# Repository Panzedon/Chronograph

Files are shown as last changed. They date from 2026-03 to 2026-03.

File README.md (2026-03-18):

# ⚡ Хронограф для страйкбола / Airsoft Chronograph

[🇺🇦 Українська](#-українська) | [🇬🇧 English](#-english)

---

## 🇺🇦 Українська

### 📌 Опис проєкту
Хронограф для страйкбольних куль 6 мм на базі мікроконтролера **STM8S103F3P6**.  
Живлення від **USB Type-C**, використання **двох ІЧ-променів (інфрачервоних)** для фіксації польоту кульки.

🎯 **Можливості:**
- 📏 Вимірювання **швидкості кулі** (м/с)
- 💥 Розрахунок **енергії пострілу** (Дж)
- 🔫 Визначення **скорострільності** (пострілів за хвилину / RPM)
- 🧠 **Енергонезалежна пам'ять:** пристрій запам'ятовує останній обраний режим та вагу кульки після вимкнення живлення.
- ⚡ **Миттєвий розрахунок:** при пострілі система одночасно обчислює швидкість, енергію та скорострільність.

### 🔧 Керування
- 🔴 **Ліва кнопка (Кнопка 1)** — вмикає/вимикає семисегментний індикатор.
- 🔵 **Права кнопка (Кнопка 2):**
    - **Коротке натискання** — перемикання між режимами відображення (Швидкість / Енергія / Скорострільність).
    - **Довге утримання** — перехід у режим **задання ваги кульки** (у грамах). 
    - **Вибір ваги:** доступні значення — **0.2г, 0.23г, 0.25г, 0.28г, 0.3г**.
    - **Збереження:** повторне довге утримання зберігає обрану вагу та повертає до основного режиму.

### ⚙️ Технічні характеристики

| Параметр | Значення |
|---|---|
| Мікроконтролер | STM8S103F3P6 |
| Живлення | USB Type-C |
| Датчики | 2 ІЧ-промені |
| Калібр | 6 мм BB (страйкбол) |

### 📂 Структура проєкту
- **Altium** — принципова схема та плата (Altium Designer) і системні файли.
- **Docs** - архів сверління для заводу, BOM і документація
- **VsCode** — середовище розробки (C, COSMIC, stm8flash, ST-LINK) і код програми.

## 📽️ Відео демонстрація роботи

У цьому відео продемонстровано процес вимірювання швидкості та скорострільності страйкбольного приводу (AEG) за допомогою розробленого хронографа. 

Дивитися відео (https://youtube.com/shorts/bznoCWF54Is)

✍️ **Автор:** Матвій Шульга

---

## 🇬🇧 English

### 📌 Project description
Chronograph for 6 mm airsoft BBs based on **STM8S103F3P6** microcontroller.  
Powered via **USB Type-C**, uses **two IR (Infrared) beams** to detect BB flight.

🎯 **Features:**
- 📏 Measure **BB velocity** (m/s)
- 💥 Calculate **shot energy** (Joules)
- 🔫 Measure **rate of fire** (rounds per minute / RPM)
- 🧠 **Non-volatile memory:** the device remembers the last measurement mode and BB weight setting after power off.
- ⚡ **Instant calculation:** a single shot triggers simultaneous calculation of velocity, energy, and rate of fire.

### 🔧 Controls
- 🔴 **Left Button (Button 1)** — LED indicator power on/off.
- 🔵 **Right Button (Button 2):**
    - **Short press** — toggles between display modes (Velocity / Energy / Rate of Fire).
    - **Long hold** — enters **BB weight setting mode** (in grams).
    - **Weight presets:** **0.2g, 0.23g, 0.25g, 0.28g, 0.3g**.
    - **Saving:** long hold again to save the selected weight and return to the measurement mode.

### ⚙️ Technical specifications

| Parameter | Value |
|---|---|
| Microcontroller | STM8S103F3P6 |
| Power supply | USB Type-C |
| Sensors | 2 IR beams |
| Caliber | 6 mm BBs |

### 📂 Project Structure
- **Altium** — Schematic design, PCB layout (Altium Designer), and project system files.
- **Docs** — Manufacturing files (Drill/Gerber), Bill of Materials (BOM), and technical documentation.
- **VsCode** — Development environment (C, COSMIC, stm8flash, ST-LINK) and source code.

## 📽️ Video Demonstration

This video demonstrates the measurement of muzzle velocity and rate of fire (ROF) for an airsoft replica (AEG) using the developed chronograph.

Watch Video (https://youtube.com/shorts/bznoCWF54Is)

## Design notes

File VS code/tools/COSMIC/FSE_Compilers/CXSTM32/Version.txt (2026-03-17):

---------------------------------
STM32 COSMIC C 32K Compiler
Version: 4.3.12 Date: 14 Dec 2023
---------------------------------
COSMIC Software CORTEX-M C Cross Compiler (LIMITED) V4.3.12 - 14 Dec 2023 - Win32-F
COSMIC Software CORTEX-M C Parser (LIMITED) V4.13.7 - 08 Nov 2023 - Win32-F
COSMIC Software CORTEX-M Code Generator (LIMITED) V4.3.12 - 14 Dec 2023 - Win32-F
COSMIC Software CORTEX-M Optimizer V4.2.12 - 14 Dec 2023 - Win32
COSMIC Software CORTEX-M Macro-Assembler (LIMITED) V4.8.1 - 14 Dec 2023 - Win32-F
COSMIC Software Linker (LIMITED) V4.12.1 - 02 Feb 2023 - Win32-F
COSMIC Software Hexa Translator V4.5.7 - 06 Sep 2023 - Win32
COSMIC Software Absolute Listing V4.5.7 - 06 Sep 2023 - Win32
COSMIC Software Librarian V4.5.7 - 06 Sep 2023 - Win32
COSMIC Software Absolute C Listing V4.5.7 - 06 Sep 2023 - Win32
COSMIC Software Object Inspector V4.5.7 - 06 Sep 2023 - Win32
COSMIC Software Print Debug Info V4.5.7 - 06 Sep 2023 - Win32
COSMIC Software ELF/DWARF Converter V4.7.6 - 11 Jan 2022 - Win32

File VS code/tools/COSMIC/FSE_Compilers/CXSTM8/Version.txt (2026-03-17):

--------------------------------------
COSMIC STM8 C Compiler Special Edition
Version: 4.6.5 Date: 22 May 2025
--------------------------------------
COSMIC Software STM8 C Cross Compiler (Special Edition) V4.6.5 - 22 May 2025 - Win32-F
COSMIC Software STM8 C Parser (Special Edition) V4.13.3 - 22 May 2025 - Win32-F
COSMIC Software STM8 Code Generator (Special Edition) V4.6.5 - 22 May 2025 - Win32-F
COSMIC Software STM8 Optimizer V4.6.5 - 22 May 2025 - Win32
COSMIC Software STM8 Macro-Assembler (Special Edition) V4.8.1 - 14 Dec 2023 - Win32-F
COSMIC Software Linker (Special Edition) V4.12.2 - 05 May 2025 - Win32-F
COSMIC Software Hexa Translator V4.5.8 - 27 Jun 2024 - Win32
COSMIC Software Absolute Listing V4.5.8 - 27 Jun 2024 - Win32
COSMIC Software Librarian V4.5.8 - 27 Jun 2024 - Win32
COSMIC Software Absolute C Listing V4.5.8 - 27 Jun 2024 - Win32
COSMIC Software Object Inspector V4.5.8 - 27 Jun 2024 - Win32
COSMIC Software Print Debug Info V4.5.8 - 27 Jun 2024 - Win32
COSMIC Software ELF/DWARF Converter V4.7.6 - 11 Jan 2022 - Win32

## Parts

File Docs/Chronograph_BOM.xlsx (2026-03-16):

Internal reference |  |  |  |  |  |  |  |  |  |  |  |  | BPC.001.BAT.001
Assembly variant |  |  |  |  |  |  |  |  |  |  |  |  | 3
Engineer(s) | Matvei Shulga
Document timestamp
Technical information |  |  |  |  |  |  |  | Additional information |  |  | Logistics information
 |  |  |  |  |  |  |  |  |  |  | Ajax warehouse |  | Replacement options
Designator | Manufacturer | Part Number | Value | Tolerance | Voltage | Component Type | Package | Quantity | Comment | Description | Ajax_1C_ID | Ajax_1C_PN | Replacement
C1 |  |  | 22µF | 20% | 10V |  | 1206 | 1 | TAJA226M010RNJ | Cap Tant Solid 22uF 10V A CASE 20%( 3.2 X 1.6 X 1.6mm) Inward L SMD 3216-18 3 Ohm 125C T/R |  |  | NONE
C2 |  |  | 10µF | 10% | 35V |  | 1206 | 1 | GCJ31CD7YA106KE02L | Ceramic Capacitor, Ceramic, 35V, 10% +Tol, 10% -Tol, X7T, 22/-33% TC, 10uF, Surface Mount, 1206 |  |  | NONE
C3, C6, C8, C10, C11 |  |  | 100nF |  |  |  | 1206 | 5 | UMK316B7104KLHT | Ceramic Capacitor, Multilayer, Ceramic, 50V, 10% +Tol, 10% -Tol, X7R, 15% TC, 0.1uF, Surface Mount, 1206 |  |  | NONE
C4, C7 |  |  | 1µF | 5% | 10V |  | 1206 | 2 | 1206ZC105JAT2A | Ceramic Capacitor, Multilayer, Ceramic, 10V, 5% +Tol, 5% -Tol, X7R, 15% TC, 1uF, Surface Mount, 1206 |  |  | NONE
C5 |  |  | 680nF |  |  |  | 0805 | 1 | CC0805KKX7R6BB684 | Ceramic Capacitor, Multilayer, Ceramic, 10V, 10% +Tol, 10% -Tol, X7R, 15% TC, 0.68uF, Surface Mount, 0805 |  |  | NONE
C9 |  |  | 100µF | 20% | 6.3V |  | 1206 | 1 | TLJA107M006R0500 | Cap Tant Solid 100uF 6.3V A CASE 20% (3.2 X 1.6 X 1.6mm) Inward L SMD 3216-18 0.5 Ohm 125C T/R |  |  | NONE
C12, C13 |  |  | 100pF |  |  |  | 1206 | 2 | 12063A101KAT2A | Ceramic Capacitor, Multilayer, Ceramic, 25V, 10% +Tol, 10% -Tol, C0G, 30ppm/Cel TC, 0.0001uF, Surface Mount, 1206 |  |  | NONE
D1 |  |  |  |  |  |  | SOT-143 | 1 | SP0503BAHTG | SP050xBA Series 8.5 V 30 pF Triple Uni-Directional TVS Avalanche Diode-SOT143-4 |  |  | NONE
DS1 | Everlight | ELT-315USOWA/S530-A3 |  |  |  |  |  | 1 | 7 Segment Indicator | Display |  |  | NONE
IC1 | TITAN MICRO ELECTRONICS | TM1637 (SOP) |  |  |  |  |  | 1 | TM1637 | Integrated Circuit |  |  | NONE
J1 |  |  |  |  | 20V |  |  | 1 | USB4110-GF-A | USB Connector, 16 Contact(s), Male, Right Angle, Surface Mount Terminal, Locking, Receptacle |  |  | NONE
LED1, LED2 | Everlight | IR333/H0-A |  |  |  |  |  | 2 | IR333 | LED |  |  | NONE
P1 |  |  |  |  |  | Standard |  | 1 | ST-Link V2 |  |  |  | NONE
Q1, Q2 | Everlight | PT333-3C |  |  |  |  |  | 2 | PT333-3C | Phototransistor |  |  | NONE
R1, R5, R7, R8, R10, R12, R13 |  |  | 10k | 1% | 200V |  | 1206 | 7 | AC1206FR-1310KL | Res Thick Film 1206 10K Ohm 1% 0.25W(1/4W) ±100ppm/°C Pad SMD T/R Automotive AEC-Q200 |  |  | NONE
R2, R3 |  |  | 5.1k | 1% | 200V |  | 1206 | 2 | ESR18EZPF5101 | Res Thick Film 1206 5.1K Ohm 1% 0.5W(1/2W) ±100ppm/C Pad SMD T/R Automotive AEC-Q200 |  |  | NONE
R4, R9 |  |  | 100 | 5% | 200V |  | 1206 | 2 | RC3216J101CS | Res Thick Film 1206 100 Ohm 5% 1/4W ±100ppm/°C Molded SMD T/R |  |  | NONE
R6, R11 |  |  | 1k | 0.1% | 25V |  | 1206 | 2 | RP73D2B1K0BTG | Res Thin Film 1206 1K Ohm 0.1% 0.25W(1/4W) ±15ppm/C Pad SMD Cut Tape Medical |  |  | NONE
SW1, SW2 |  |  |  |  |  |  |  | 2 | FSM4JSMATR | Keypad Switch, 1 Switches, SPST, Momentary-tactile, 0.05A, 24VDC, 2.06N, Solder Terminal, Surface Mount-straight |  |  | NONE
U1 |  |  |  |  |  |  | SOP | 1 | AMS1117-3.3 | Fixed Positive LDO Regulator, 3.3V, 1.3V Dropout, PDSO3 |  |  | NONE
U2 |  |  |  |  |  | Standard | TSSOP-20 STMicroelectronics | 1 | STM8S103F3P6 | STM8 series Microcontroller IC 8-Bit 16MHz 8KB (8K x 8) FLASH 20-TSSOP |  |  | NONE
U3 |  |  |  |  |  |  | QFN | 1 | CP2104-F03-GM | USB-to-UART 1-CH 576byte FIFO 3.3V Automotive 24-Pin QFN EP Tube |  |  | NONE
U4 |  |  |  |  |  |  | SOP | 1 | LM393DT | Comparator, 2 Func, 9000uV Offset-Max, 1300ns Response Time, BIPolar, PDSO8 |  |  | NONE
VR1 | Bourns | 3362P-1-205LF |  |  |  |  |  | 1 | 3362P-1-205LF | Variable Resistor |  |  | NONE
 |  |  |  |  |  |  |  |  |  |  |  |  | NONE
 |  |  |  |  |  |  |  |  |  |  |  |  | NONE
 |  |  |  |  |  |  |  |  |  |  |  |  | NONE
 |  |  |  |  |  |  |  |  |  |  |  |  | NONE
 |  |  |  |  |  |  |  |  |  |  |  |  | NONE
 |  |  |  |  |  |  |  |  |  |  |  |  | NONE
 |  |  |  |  |  |  |  |  |  |  |  |  | NONE
 |  |  |  |  |  |  |  |  |  |  |  |  | NONE
 |  |  |  |  |  |  |  |  |  |  |  |  | NONE
 |  |  |  |  |  |  |  |  |  |  |  |  | NONE
 |  |  |  |  |  |  |  |  |  |  |  |  | NONE
 |  |  |  |  |  |  |  |  |  |  |  |  | NONE
 |  |  |  |  |  |  |  |  |  |  |  |  | NONE
 |  |  |  |  |  |  |  |  |  |  |  |  | NONE
 |  |  |  |  |  |  |  |  |  |  |  |  | NONE
 |  |  |  |  |  |  |  |  |  |  |  |  | NONE
 |  |  |  |  |  |  |  |  |  |  |  |  | NONE
 |  |  |  |  |  |  |  |  |  |  |  |  | NONE
 |  |  |  |  |  |  |  |  |  |  |  |  | NONE
 |  |  |  |  |  |  |  |  |  |  |  |  | NONE
 |  |  |  |  |  |  |  |  |  |  |  |  | NONE
 |  |  |  |  |  |  |  |  |  |  |  |  | NONE
 |  |  |  |  |  |  |  |  |  |  |  |  | NONE
 |  |  |  |  |  |  |  |  |  |  |  |  | NONE
 |  |  |  |  |  |  |  |  |  |  |  |  | NONE
 |  |  |  |  |  |  |  |  |  |  |  |  | NONE

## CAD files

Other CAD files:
VS code/tools/COSMIC/stsw-stm8069/STM8S_StdPeriph_Lib/Project/STM8S_StdPeriph_Template/STVD/Cosmic/stm8s103.stp
VS code/tools/COSMIC/stsw-stm8069/STM8S_StdPeriph_Lib/Project/STM8S_StdPeriph_Template/STVD/Raisonance/stm8s003.stp
VS code/tools/COSMIC/stsw-stm8069/STM8S_StdPeriph_Lib/Project/STM8S_StdPeriph_Template/STVD/Cosmic/stm8af52ax.stp
VS code/tools/COSMIC/stsw-stm8069/STM8S_StdPeriph_Lib/Project/STM8S_StdPeriph_Template/STVD/Raisonance/stm8af62ax.stp
VS code/tools/COSMIC/stsw-stm8069/STM8S_StdPeriph_Lib/Project/STM8S_StdPeriph_Template/STVD/Cosmic/stm8af626x.stp
VS code/tools/COSMIC/stsw-stm8069/STM8S_StdPeriph_Lib/Project/STM8S_StdPeriph_Template/STVD/Raisonance/stm8s207.stp
VS code/tools/COSMIC/stsw-stm8069/STM8S_StdPeriph_Lib/Project/STM8S_StdPeriph_Template/STVD/Cosmic/stm8s208.stp
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

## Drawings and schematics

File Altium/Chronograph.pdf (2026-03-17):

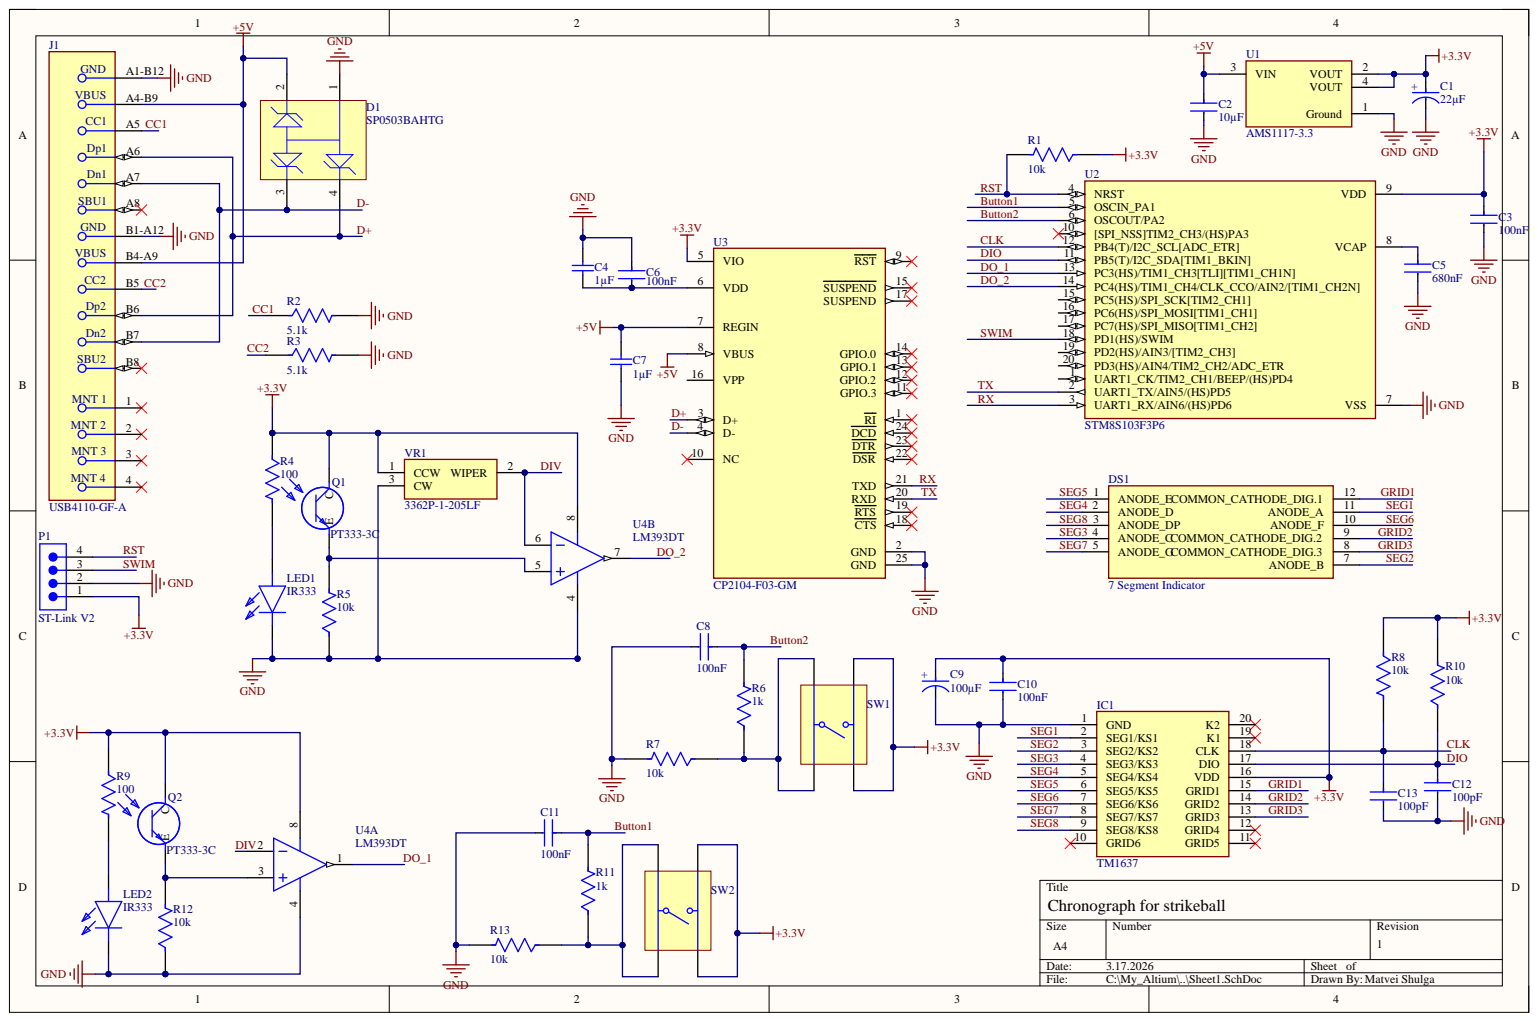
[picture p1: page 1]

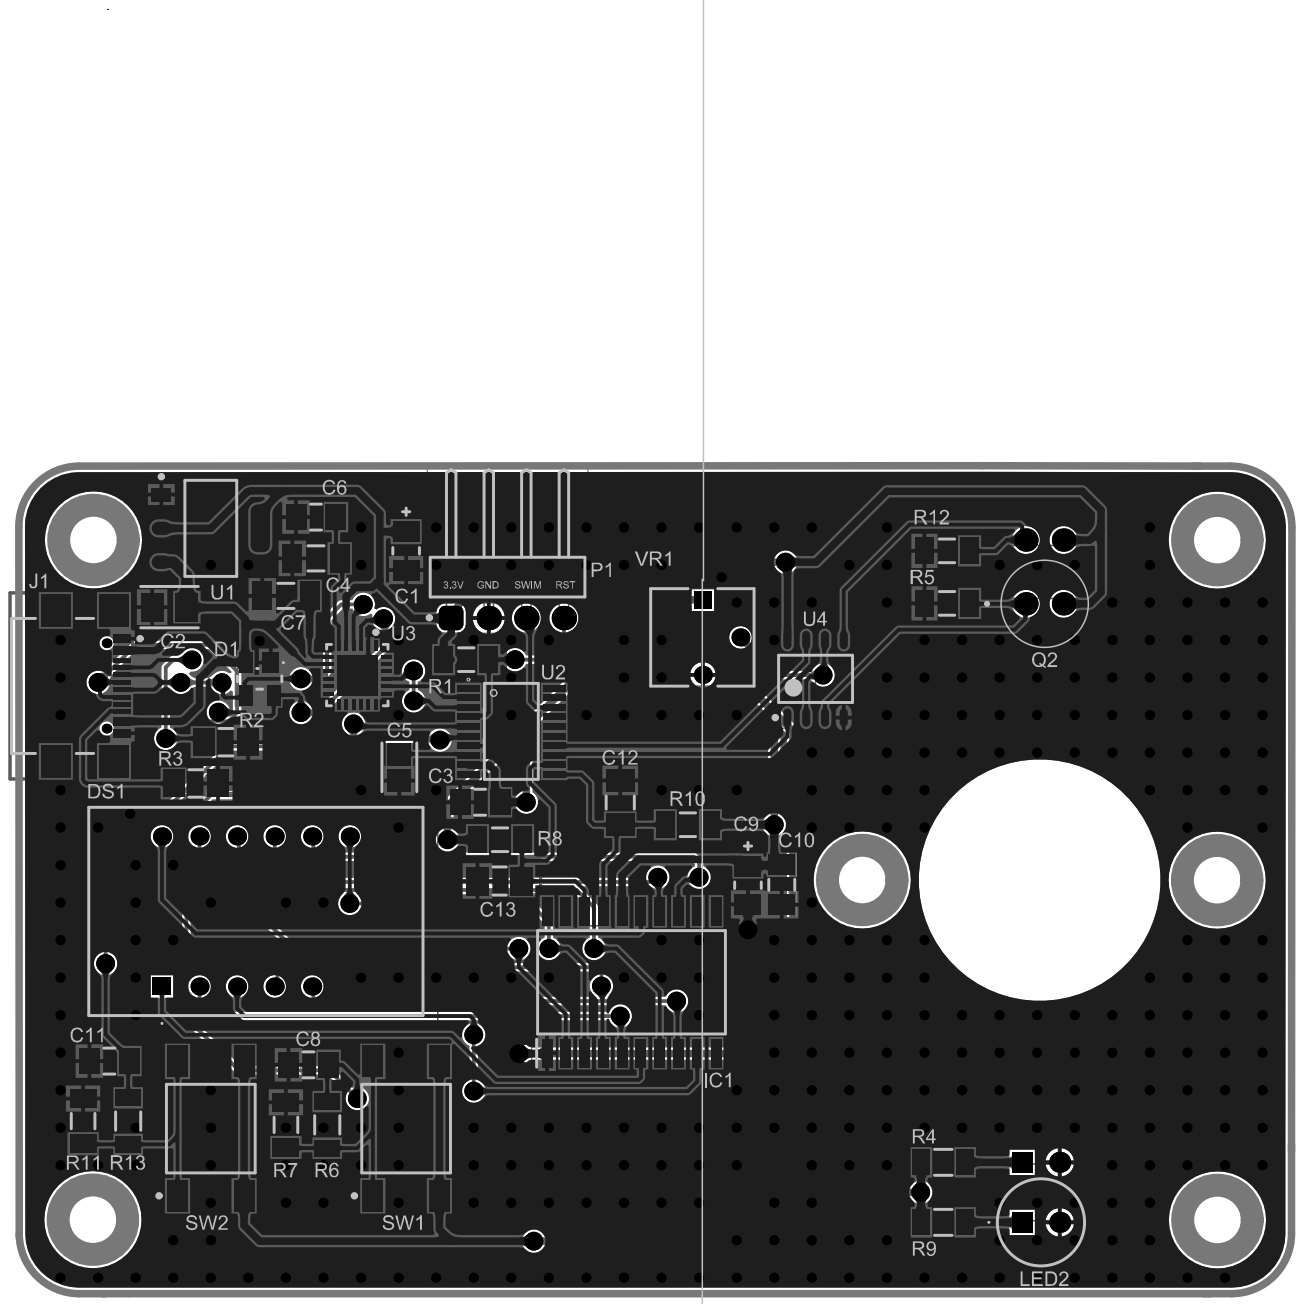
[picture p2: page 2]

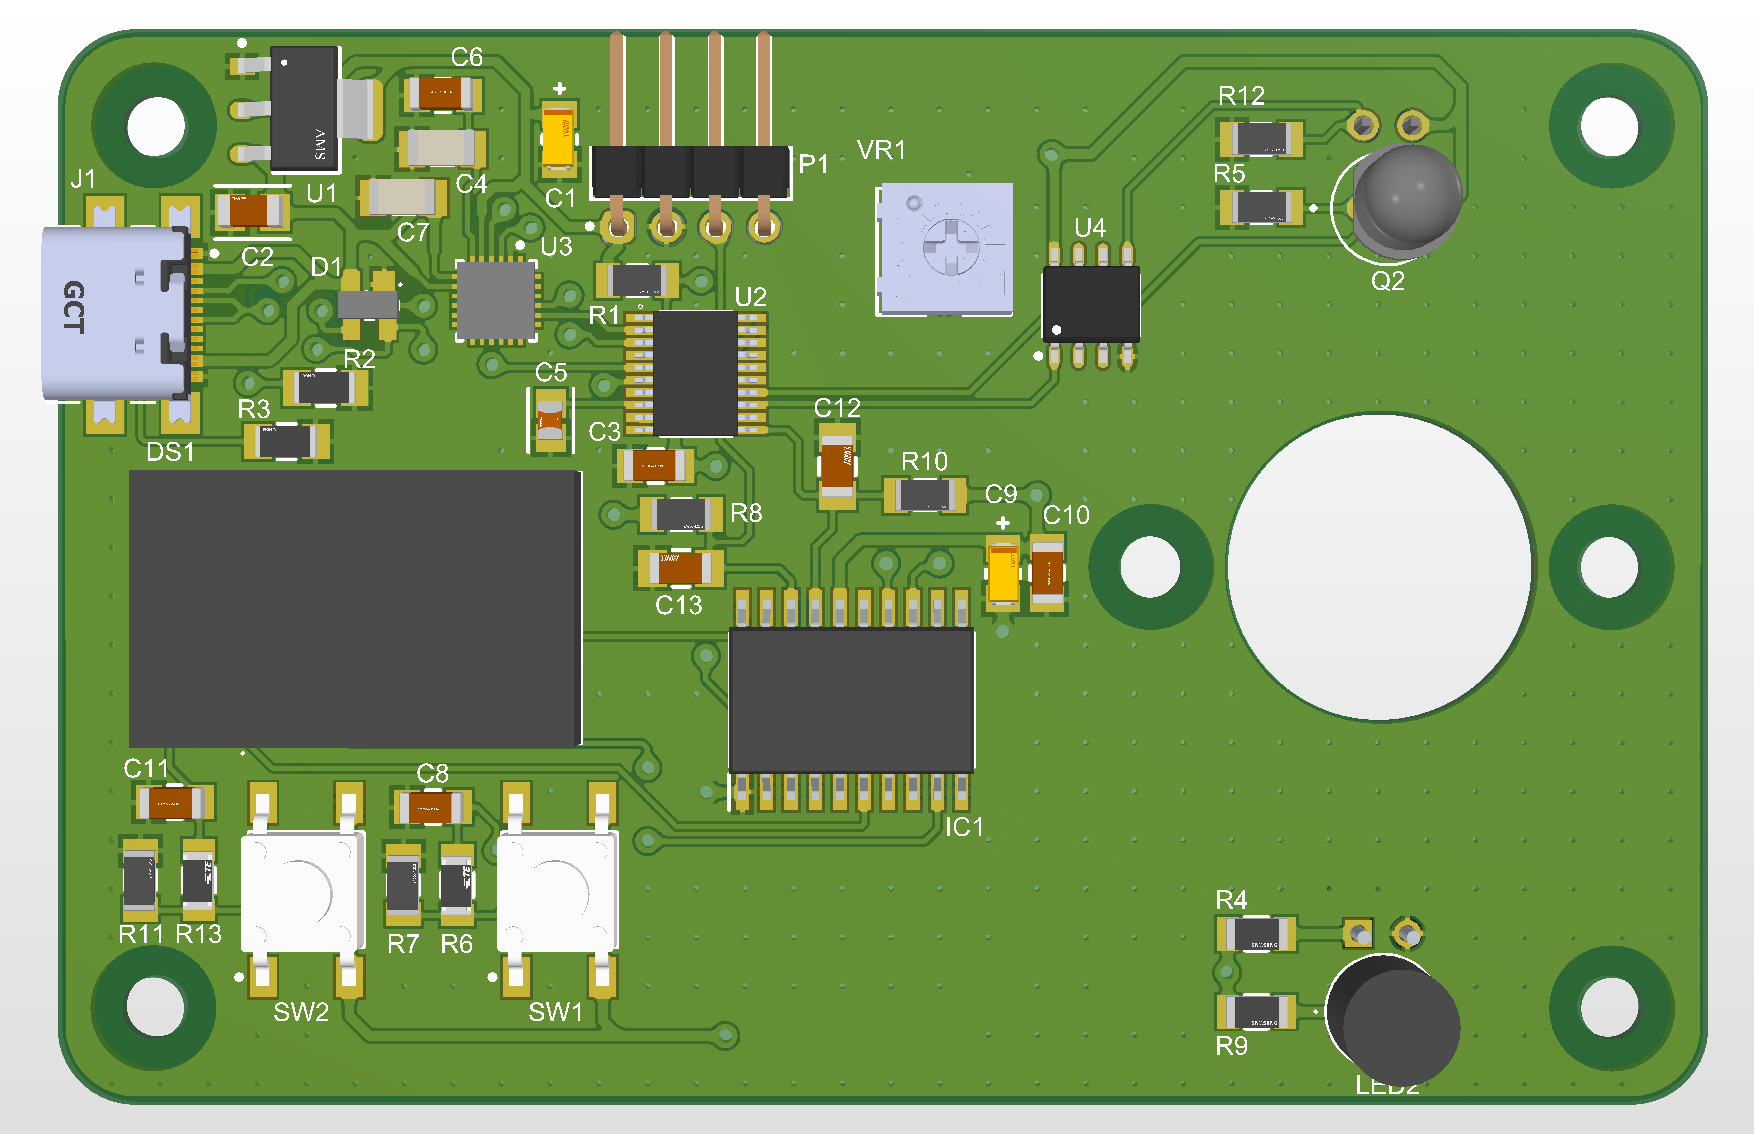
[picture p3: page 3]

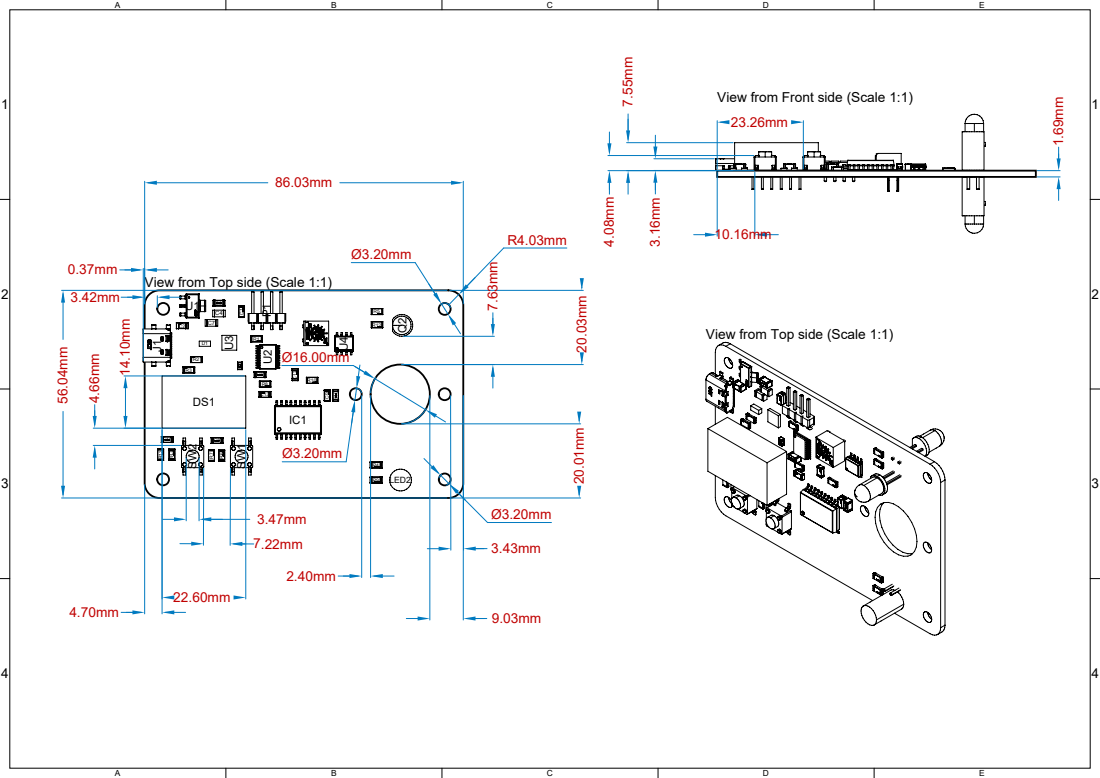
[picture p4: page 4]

View from Front side (Scale 1:1)

View from Top side (Scale 1:1)

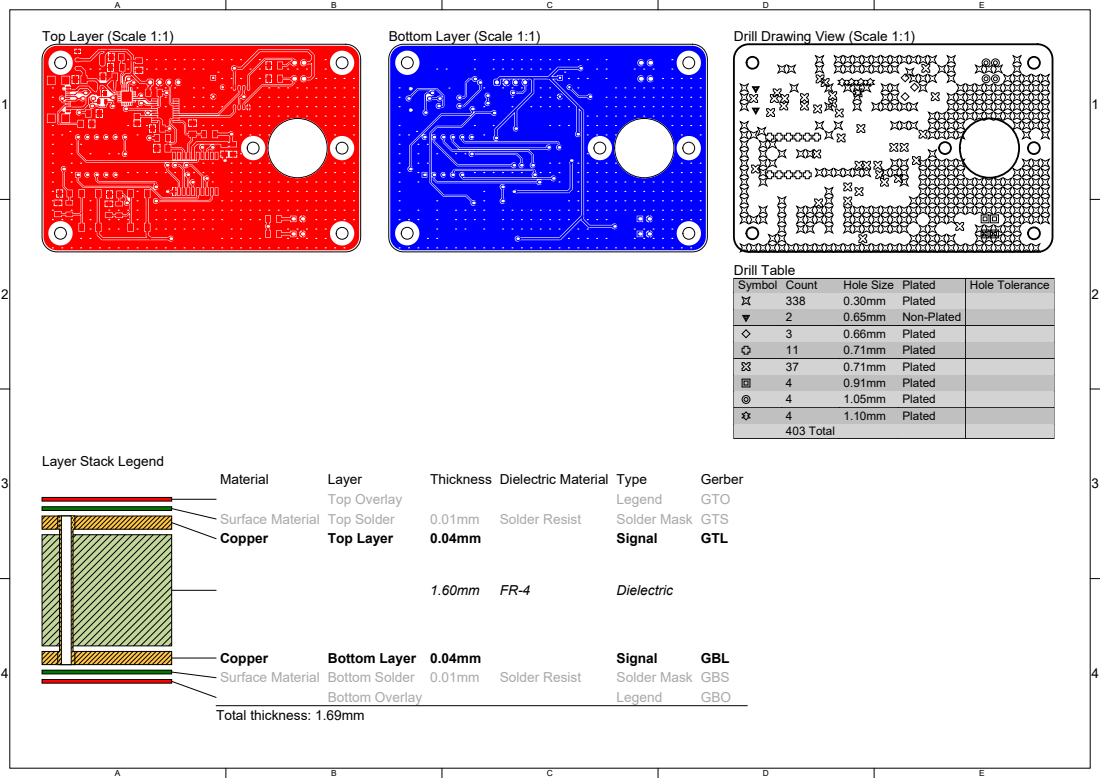
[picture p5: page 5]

Symbol | Count | Hole Size | Plated | Hole Tolerance

338 | 0.30mm | Plated
2 | 0.65mm | Non-Plated
3 | 0.66mm | Plated
11 | 0.71mm | Plated
37 | 0.71mm | Plated
4 | 0.91mm | Plated
4 | 1.05mm | Plated
4 | 1.10mm | Plated
403 Total

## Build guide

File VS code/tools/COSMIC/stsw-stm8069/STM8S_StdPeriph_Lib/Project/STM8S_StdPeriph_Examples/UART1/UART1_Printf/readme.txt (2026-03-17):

/** @page UART1_Printf Retarget the C library printf function to the UART1

  @verbatim
  ******************** (C)COPYRIGHT 2014 STMicroelectronics *******************
  * @file    UART1/UART1_Printf/readme.txt 
  * @author  MCD Application Team
  * @version V2.0.4
  * @date    26-April-2018
  * @brief   Description of the UART1 retarget C library Example.
  ******************************************************************************
  *
  * Licensed under MCD-ST Liberty SW License Agreement V2, (the "License");
  * You may not use this file except in compliance with the License.
  * You may obtain a copy of the License at:
  *
  *        http://www.st.com/software_license_agreement_liberty_v2
  *
  * Unless required by applicable law or agreed to in writing, software 
  * distributed under the License is distributed on an "AS IS" BASIS, 
  * WITHOUT WARRANTIES OR CONDITIONS OF ANY KIND, either express or implied.
  * See the License for the specific language governing permissions and
  * limitations under the License.
  *
  ******************************************************************************
  @endverbatim

  @par Example description
  This example shows how to retarget the C library printf/getchar functions to the
  UART1. 
  This implementation output the printf message on the Hyperterminal using UART1 
  and keep waiting a character to be entered by the user.

  The UART1 is configured as follows:
    - BaudRate = 115200 baud  
    - Word Length = 8 Bits
    - One Stop Bit
    - No parity
    - Receive and transmit enabled
    - UART1 Clock disabled
 
  @par Directory contents

  - UART1\UART1_Printf\main.c           Main file containing the "main" function
  - UART1\UART1_Printf\stm8s_conf.h     Library Configuration file
  - UART1\UART1_Printf\stm8s_it.c       Interrupt routines source
  - UART1\UART1_Printf\stm8s_it.h       Interrupt routines declaration

  @par Hardware and Software environment

  - This example runs on STM8S High density and Low density devices and on STM8A
    High density devices.  
      
  - This example has been tested with STMicroelectronics STM8/128-EVAL evaluation 
    board and can be easily tailored to any other development board.

  - STM8/128-EVAL Set-up
     - Connect a null-modem female/female RS232 cable between the DB9 connector 
       CN13 and PC serial port.  

     - Hyperterminal configuration:
       - Word Length = 8 Bits
       - One Stop Bit
       - No parity
       - BaudRate = 115200 baud
       - flow control: None 

  @par How to use it ?

  In order to make the program work, you must do the following :

  - Copy all source files from this example folder to the template folder under
    Project\Template
  - Open your preferred toolchain 
  - Rebuild all files and load your image into target memory
  - Run the example
  
  @note
  - High-Density STM8A devices are the STM8AF52xx STM8AF6269/8x/Ax,
    STM8AF51xx, and STM8AF6169/7x/8x/9x/Ax microcontrollers where the Flash memory
    density ranges between 32 to 128 Kbytes
  - Medium-Density STM8A devices are the STM8AF622x/4x, STM8AF6266/68,
    STM8AF612x/4x, and STM8AF6166/68 microcontrollers where the Flash memory 
    density ranges between 8 to 32 Kbytes
  - High-Density STM8S devices are the STM8S207xx, STM8S007 and STM8S208xx microcontrollers
    where the Flash memory density ranges between 32 to 128 Kbytes.
  - Medium-Density STM8S devices are the STM8S105x and STM8S005 microcontrollers
    where the Flash memory density ranges between 16 to 32-Kbytes.
  - Low-Density STM8S devices are the STM8S103xx, STM8S003, STM8S001 and STM8S903xx microcontrollers
    where the Flash density is 8 Kbytes.
      
 * <h3><center>&copy; COPYRIGHT STMicroelectronics</center></h3>
 */

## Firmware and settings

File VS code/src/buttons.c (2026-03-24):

#include "buttons.h"

#define BTN1_PIN (1 << 1) /* PA1 */
#define BTN2_PIN (1 << 2) /* PA2 */

#define DEBOUNCE_TIME_MS 30
#define LONG_PRESS_TIME_MS 1000


typedef struct {
    unsigned int  counter;    /* Лічильник мілісекунд утримання */
    unsigned char state;      /* 0 = відпущена, 1 = натиснута, 2 = утримання */
    btn_event_t   event;      /* Готова подія для передачі в main */
} button_state_t;

static button_state_t btns[2];

/**
 * @brief Ініціалізація портів вводу/виводу для кнопок та таймера антибрязкоту.
 * @details Налаштовує піни PA1 та PA2 на вхід (без підтяжки/переривань).
 * Скидає стан внутрішніх структур кнопок. Налаштовує TIM4 для 
 * генерації переривань або встановлення прапорців кожну мілісекунду.
 */
void Buttons_Init(void) {
    PA_DDR &= ~(BTN1_PIN | BTN2_PIN);
    PA_CR1 &= ~(BTN1_PIN | BTN2_PIN);
    PA_CR2 &= ~(BTN1_PIN | BTN2_PIN);

    btns[0].counter = 0; btns[0].state = 0; btns[0].event = EVENT_NONE;
    btns[1].counter = 0; btns[1].state = 0; btns[1].event = EVENT_NONE;

    TIM4_PSCR = 0x07; 
    TIM4_ARR  = 124;  
    
    /* TIM4_IER |= 0x01; */
    TIM4_CR1 |= 0x01; 
}


/**
 * @brief Кінцевий автомат (стейт-машина) обробки фізичного стану кнопок.
 * @details Зчитує фізичний стан пінів кнопок. Фільтрує брязкіт контактів 
 * (затримка DEBOUNCE_TIME_MS). Відстежує час утримання кнопки для генерації 
 * подій короткого (EVENT_SHORT_PRESS) або довгого (EVENT_LONG_PRESS) натискання.
 * Повинна викликатися рівно раз на 1 мс.
 */
void Buttons_Tick(void) {
    unsigned char i;
    unsigned char pins_state;
    unsigned char is_pressed[2];

    pins_state = PA_IDR; /* Читаємо весь порт A один раз */

    is_pressed[0] = (pins_state & BTN1_PIN);
    is_pressed[1] = (pins_state & BTN2_PIN);

    for (i = 0; i < 2; i++) {
        if (is_pressed[i]) {
            if (btns[i].state == 0) {
                btns[i].state = 1; 
            }
            
            if (btns[i].state == 1) {
                btns[i].counter++; 
                
                if (btns[i].counter >= LONG_PRESS_TIME_MS) {
                    btns[i].event = EVENT_LONG_PRESS; 
                    btns[i].state = 2; 
                }
            }
        } else {
            if (btns[i].state == 1) {
                if (btns[i].counter >= DEBOUNCE_TIME_MS) {
                    btns[i].event = EVENT_SHORT_PRESS; 
                }
            }
            btns[i].state = 0;
            btns[i].counter = 0;
        }
    }
}

/**
 * @brief Повертає зареєстровану подію для вказаної кнопки та скидає її.
 * @details Безпечно (з відключенням переривань) читає подію з буфера кнопки.
 * Після читання подія обнуляється, щоб уникнути повторного спрацьовування.
 * @param btn_id Ідентифікатор кнопки (BTN_1_LASER або BTN_2_MENU).
 * @return btn_event_t Тип події (EVENT_NONE, EVENT_SHORT_PRESS, EVENT_LONG_PRESS).
 */
btn_event_t Buttons_GetEvent(button_id_t btn_id) {
    /* СУВОРИЙ C89: Змінна на початку */
    btn_event_t current_event;
    
    _asm("sim"); 
    
    current_event = btns[btn_id].event; 
    btns[btn_id].event = EVENT_NONE;    
    
    _asm("rim"); 
    
    return current_event;
}

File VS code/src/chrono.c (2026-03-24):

#include "chrono.h"
#include "iostm8s103.h"

volatile uint8_t shot_ready = 0;
volatile uint16_t time_start = 0;
volatile uint16_t time_end = 0;
volatile uint16_t overflow_count = 0; /* Лічильник кіл (переповнень) таймера */

/**
 * @brief Ініціалізація апаратної частини хронографа (Таймер 1).
 * @details Налаштовує TIM1 для роботи на максимальній частоті (без дільника).
 * Налаштовує піни PC3 (перший датчик) та PC4 (другий датчик) на вхід.
 * Активує режим Input Capture для обох каналів, але переривання дозволяє 
 * лише для першого датчика (очікування початку пострілу).
 */
void Chrono_Init(void) {
    CLK_PCKENR1 |= 0x80;
    TIM1_PSCRH = 0;      
    TIM1_PSCRL = 0;      
    TIM1_ARRH = 0xFF;    
    TIM1_ARRL = 0xFF;    

    PC_CR2 &= ~((1<<3) | (1<<4));
    EXTI_CR1 &= ~(0x30);          

    PC_DDR &= ~((1<<3) | (1<<4)); 
    PC_CR1 |= ((1<<3) | (1<<4)); 
    
    TIM1_CCMR3 = 0x31; 
    TIM1_CCMR4 = 0x31; 
    TIM1_CCER2 = 0x33; 

    /* Вмикаємо захоплення лише для 1-го променя при старті */
    TIM1_IER = (1<<3); 
    TIM1_CR1 |= 0x01;  
}

/**
 * @brief Перевіряє статус готовності вимірювання.
 * @return uint8_t 1, якщо кулька успішно пройшла обидва датчики, інакше 0.
 */
uint8_t Chrono_IsReady(void) {
    return shot_ready;
}

/**
 * @brief Обчислює загальний час польоту кульки у тіках таймера.
 * @details Формує 32-бітне значення на основі різниці захоплених значень 
 * (time_end - time_start) та кількості повних переповнень таймера (overflow_count).
 * @return uint32_t Загальний час у тіках (1 тік = 1/16 мкс при 16 МГц).
 */
uint32_t Chrono_GetTotalTicks(void) {
    uint32_t total;
    /* Формула: (Кола * 65536) + Кінець - Старт */
    //_asm("sim"); // Вимикаємо переривання на час читання
    total = ((uint32_t)overflow_count * 65536UL) + time_end - time_start;
    //_asm("rim"); // Вмикаємо назад
    return total;
}

/**
 * @brief Скидання стану хронографа для готовності до наступного пострілу.
 * @details Обнуляє прапорець готовності. Вимикає другий датчик та переривання 
 * по переповненню. Знову активує (взводить) переривання першого датчика.
 */
void Chrono_Reset(void) {
    shot_ready = 0;
    
    /* Глушимо обидва промені та переривання переповнення (UIE) */
    TIM1_IER &= (uint8_t)(~((1<<3) | (1<<4) | 0x01)); 
    TIM1_SR1 = (uint8_t)(~((1<<3) | (1<<4) | 0x01));  
    
    /* Зводимо ТІЛЬКИ ПЕРШИЙ промінь для нового пострілу */
    TIM1_IER |= (1<<3); 
}


/**
 * @brief Обробник переривання по переповненню TIM1 (Update Interrupt).
 * @details Викликається щоразу, коли лічильник таймера доходить до 0xFFFF 
 * і скидається в 0. Збільшує лічильник "кіл" (overflow_count), який потрібен 
 * для вимірювання повільних кульок.
 */
FAR_ INTERRUPT_ void Chrono_OverflowInterrupt(void) {
    overflow_count++;
    TIM1_SR1 = (uint8_t)(~0x01); /* Швидко скидаємо прапорець UIF */
}


/**
 * @brief Обробник переривань по захопленню (Input Capture) TIM1.
 * @details Реалізує апаратну "засувку" для вимірювання швидкості:
 * 1. При спрацьовуванні першого датчика (PC3) - зберігає час старту, 
 * вимикає себе, обнуляє лічильник переповнень та вмикає другий датчик.
 * 2. При спрацьовуванні другого датчика (PC4) - зберігає час фінішу, 
 * вимикає себе, зупиняє лічильник переповнень та піднімає прапорець `shot_ready`.
 */
FAR_ INTERRUPT_ void Chrono_HandleInterrupt(void) {
    uint8_t flags = TIM1_SR1;
    
    /* СПРАЦЮВАВ ПЕРШИЙ ДАТЧИК (ВХІД) */
    if (flags & (1<<3)) {
        time_start = ((uint16_t)TIM1_CCR3H << 8) | TIM1_CCR3L; 
        
        /* Засувка: Глушимо 1-й, чистимо 2-й, Вмикаємо 2-й */
        TIM1_IER &= (uint8_t)(~(1<<3)); 
        TIM1_SR1 = (uint8_t)(~(1<<4)); 
        TIM1_IER |= (1<<4); 
        
        /* Запускаємо лічильник кіл! */
        overflow_count = 0; 
        TIM1_SR1 = (uint8_t)(~0x01); /* Чистимо сміттєвий прапорець переповнення */
        TIM1_IER |= 0x01;            /* Вмикаємо переривання Update (UIE) */

        TIM1_SR1 = (uint8_t)(~(1<<3)); /* Чистимо прапорець 1-го променя */
    }
    
    /* СПРАЦЮВАВ ДРУГИЙ ДАТЧИК (ВИХІД) */
    else if (flags & (1<<4)) {
        time_end = ((uint16_t)TIM1_CCR4H << 8) | TIM1_CCR4L;
        shot_ready = 1; 
        
        /* Засувка: Глушимо 2-й промінь і зупиняємо лічильник кіл (UIE) */
        TIM1_IER &= (uint8_t)(~((1<<4) | 0x01)); 
        
        TIM1_SR1 = (uint8_t)(~(1<<4)); /* Чистимо прапорець 2-го променя */
    }
}

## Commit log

2025-09-03 Added files from Altium
    [Ajax_Project_1.PrjPcb, PcbLib1.PcbLib, Schlib1.SchLib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]
2025-09-04 Changed name of project in Altium
    [Chronograph.PrjPcb, Sheet1.SchDoc]
2025-09-07 Added a resistor for each laser
    [Sheet1.SchDoc]
2025-09-24 Changed in scheme buttons
    [Sheet1.SchDoc]
2025-10-08 Changed a few resistors
    [Sheet1.SchDoc]
2025-10-08 Added a connector for UART
    [Sheet1.SchDoc]
2025-10-14 Added CP2104
    [Sheet1.SchDoc]
2025-10-15 Changed resistors and capacitors for form 1206
    [Chronograph.PrjPcb, PCB1.PcbDoc, PcbLib1.PcbLib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]
2025-11-03 PCB design v1
    [Chronograph.PrjPcb, PCB1.PcbDoc, Sheet1.SchDoc]
2025-11-11 PCB v2
    [Chronograph.PrjPcb, PCB1.PcbDoc, Sheet1.SchDoc]
2025-11-17 Changed USB, TM1637
    [Chronograph.PrjPcb, PCB1.PcbDoc, Sheet1.SchDoc]
2025-11-24 resistors and capacitors were placed on one side
    [PCB1.PcbDoc, PcbLib1.PcbLib, Schlib1.SchLib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]
2026-03-16 Додав документацію, BOM, працюючий код
    [Chronograph.PrjPcb, Chronograph.SCHLIB, Chronograph.xlsx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]
2026-03-17 v1.1 pcb + final code with tools
    [Chronograph.PrjPcb, PCB1.PcbDoc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]
2026-03-24 ВDesigned the code and finalized the logic
